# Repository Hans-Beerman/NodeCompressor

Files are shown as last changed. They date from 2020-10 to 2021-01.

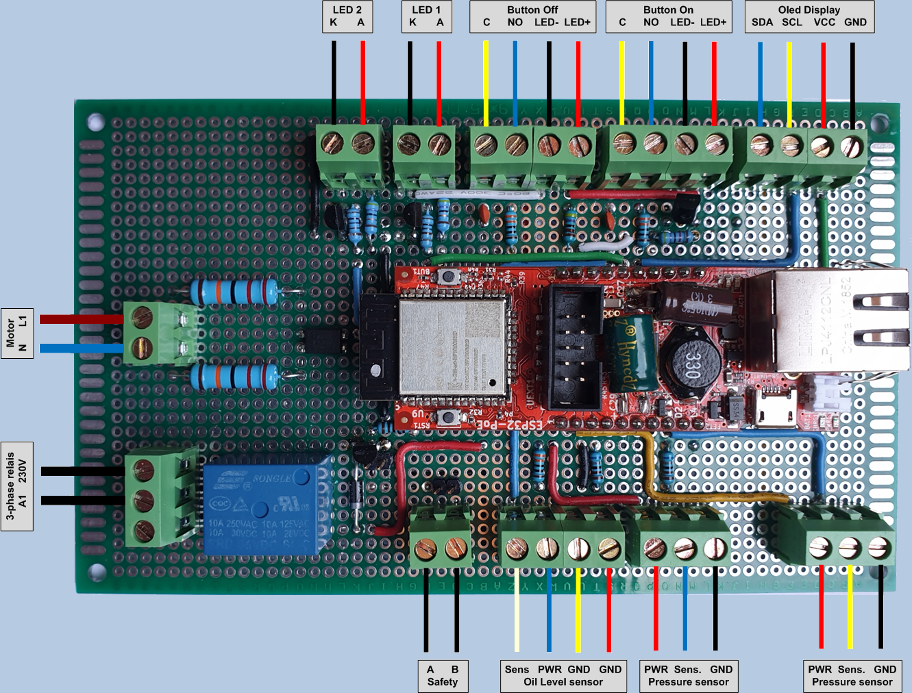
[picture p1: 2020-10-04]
Photos/Aansluitingen print V0.1 20200427.png

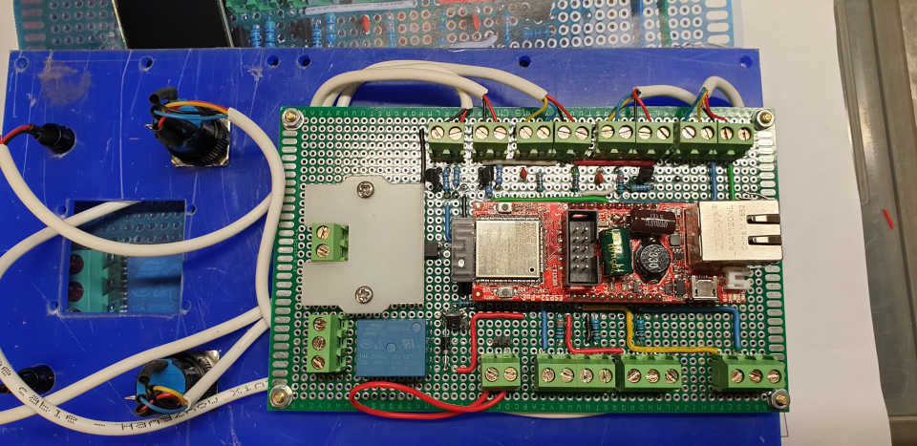
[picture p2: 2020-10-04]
Photos/CompressorNode-005.jpg

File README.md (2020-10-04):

**NodeCompressor**

NodeCompressor is a node, used at the MakerSpace Leiden, to control the main compressor. This repository has the following subdirs:

- **Drawings:**

Schematic of the wiring between the different modules used

- **KiCad\_files:**

The design of the PCB for the Node/Controller. De PCB in this design is not meant to be used for a real PCB. It is used as guideline for a handmade PCB

- **Photos:**

Some photos of the Node made.

- **PlatformIO\_Files:**

The source code for the Node and the display used. For the development of this software PlatformIO is used, an Extension on Visual Studio Code.

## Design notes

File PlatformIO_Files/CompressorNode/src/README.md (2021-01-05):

**Source code CompressorNode Makerspace Leiden**

Current version: V0.19 Concept

This repository contains the source code for the CompressorNode used at the Makerspace Leiden.

This CompressorNode is based on the use of the Olimex ESP32\_PoE. This small processor board is plugged on a backplane, details about this backplane can be found here, in KiCad files/CompressorNode:

[https://github.com/Hans-Beerman/NodeCompressor](https://github.com/Hans-Beerman/NodeCompressor)

This software is developed with Visual Studio Code in combination with the extension PlatformIO.

**This CompressorNode (the hardware in combination with the software) has the following features:**

- _Button On_: to manual switch on the compressor or cancel a manual switch off, waiting for the motor to stop running; 
- _Button Off_: to manual switch off the compressor, if the motor of the compressor is still running, switch off will be posponed until de motor is switched off by the pressure switch of the compressor. Pressing this switch for > 5s (when the motor is running) the compressor is switched off immediately;
- _Button On + Button Off_: if both buttons are pressed together for more than 5 seconds, while calibration mode is disabled, calibration mode will be disabled. Pressing both buttons together while calibration mode is enabled, calibration mode is disabled immediately. Also the duratution counters are saved in flash, every time calibration mode is enabled;
- _but1_: also used to toggle info / calibration mode on or off. but1 is the second button of the ESP32-PoE module. Press this button, when the node is running (the boot screen is not shown anymore). When info calibration mode is active each second e.g. the IP address and calibration info is logged to MQTT and telnet etc. Also the duratution counters are saved in flash, every time this button is pressed;
- _Automatic switch on_: switch the compressor on by means of dedicated MQTT messages
- _Automatic switch off_: switch the compressor off by means of dedicated MQTT mesages
- _Timeout_: the compressor will automatically switch off after a certain (in source code) configured timeout, currently after 60 minutes. Pressing Button On again (or sending MQTT command), while the compressor is switched on, will extend the timeout with 60 minutes. The auto switch off time will also be extended, with 60 minutes, when the compressor switches the motor of the compressor on or off;
- _Late hour disable_: after a configured time in the evening (currently 22:00 h) and before a configured time in the morning (currently 08:00 h) the compressor is disabled to prevent too much noise for our neighbors. This means the compressor will not start automatically by means of MQTT messages. Also the compressor will not start if the Button On is pressed normally;
- _Overrule late hour disable_: the late hour disable function can be overruled by pressing the Button On continuously for more than 10 seconds;
- _230VAC relais output:_ to switch the compressor on or off;
- _230VAC opto coupler input:_ This input is connected to one of the phases of the 3-phase motor of the compressor to detect if the motor is running or not;
- _2 LED&#39;s_: for signaling purposes. LED1 is on continuously when the compressor is switched on. LED2 is on continuously when the motor in the compressor is switched on. LED1 will flash for 5 s with 200 ms intervals if Button On is pressed during late hour disable. Both LED&#39;s will flash simultaneously with 600 ms intervals if there is an error which make it impossible to operate the compressor. The LED&#39;s will flash until the error is solved. The following two errors will disable de compressor:
  - Oil level too low;
  - Temperature to high;
- _Measurement of the machine temperature_: the temperature of the compressor is measured and reported via MQTT. The temperature is also shown on the display of the node. There are 2 temperature sensors, one is measuring the temperture of the motor, the other measures the temperature of the compressor;
- _Measurement of the oil level_: The oil level of the compressor is measured and reported via MQTT. This pressure is also shown on the display of the node;
- _Measurement of air pressure_: The air pressure, as produced by the compressor is measured and reported via MQTT. This pressure is also shown on the display of the node;
- _Status show on display_: There is a small Oled display (128x128 pixels) which shows status information about the node and the compressor.

**Setup of the software development environment**

See [https://github.com/dirkx/AccesSystem/tree/master/lib-arduino/ACNode](https://github.com/dirkx/AccesSystem/tree/master/lib-arduino/ACNode) for an introduction of how the software development environment can be setup. The description here however is based on the use of the Arduino software development tool. It will give you information about the libraries needed to compile the source code of the compressor node.

In addition to this description the following libraries are needed:

- _NTP_: NTP by Stefan Staub (#include <NTP.h>;) current version 1.4.

For more information about this library see:

[https://platformio.org/lib/show/5438/NTP](https://platformio.org/lib/show/5438/NTP)

This library is used to collect the correct local time via NTP;

- _DallasTemperature_: DallasTemperature by Miles Burton (#include <DallasTemperature.h>), current version 3.6.1, this library is used for the one wire temperature sensor based on the DS18B20;
- _U8x8lib_: U8g2 library by oliver (#include <U8x8lib.h>), current version 2.28.2, this library is used for the 128x128 pixels Oled display used.

WARNING:
The #define MQTT_MAX_PACKET_SIZE 254, in PubSubClient.h is overrulled in platformio.ini and set to 768:
In platformio,ini:
build_flags =
  '-DMQTT_MAX_PACKET_SIZE=768'

**Configuratie PlatformIO**

The configuration for this Project in PlatformIO is stored in the platformio.ini file, the content of this file is shown next, the IP address (192.168.5.95) is the current IP address of the node in the Makerspace, please change this to the correct IP address, given by the network to which the node is connected:

_;PlatformIO Project Configuration File_

_;_

_; Build options: build flags, source filter_

_; Upload options: custom upload port, speed and extra flags_

_; Library options: dependencies, extra library storages_

_; Advanced options: extra scripting_

_;_

_; Please visit documentation for the other options and examples_

_; https://docs.platformio.org/page/projectconf.html_

_[env:esp32-poe]_

_platform = espressif32_

_board = esp32-poe_

_framework = arduino_

_; enable ota_

_upload\_protocol = espota_

_upload\_port = 192.168.5.95_

_upload\_flags =_

_--port=8266_

_--auth=MyPassWoord_

_;upload\_port = /dev/ttyUSB0_

_monitor\_speed = 115200_

_board\_build.partitions = huge\_app.csv_

_; add local libraries_
_lib_deps =_
  _PubSubClient_
  _bblanchon/ArduinoJson_
  _Adafruit MAX31856 library_
  _PID_
  _ESP32WebServer_
  _NTP_
  _olikraus/U8g2_
  _milesburton/DallasTemperature_
  _adafruit/Adafruit GFX Library_
  _adafruit/Adafruit SSD1306_

_; evaluate C/C++ Preprocessor conditional syntax_
_lib\_ldf\_mode = deep+_

_monitor\_speed = 115200_
_board\_build.partitions = huge\_app.csv_

_build\_flags =_
  _; for debugging use next flag, otherwise make it comment_
  _;'-DDEBUGIT'_
  _; Default packet size is to small_
  _'-DMQTT\_MAX\_PACKET\_SIZE=768'_
  _; mqtt server address if not mqtt server MakerSpace_
  _;'-DMQTT\_SERVER="10.0.0.145"'_

**Configuration of the behaviour of the Node**

With the following parameters in the source code the behaviour of the node can be controlled:

- _Temperature limits:_

In main.cpp:

// temperature sensor

#define TEMP\_SENSOR\_LABEL1 ("Compressor") // label used in logging for temp. sensor 1

#define TEMP\_SENSOR\_LABEL2 ("Motor") // label used in logging for temp. sensor 2

#define TEMP\_REPORT\_ERROR1 ("temperature_sensor_1_(compressor)_error") // label used in reporting for temp. sensor 1

#define TEMP\_REPORT\_WARNING1 ("temperature_sensor_1_(compressor)_warning") // label used in reporting for temp. sensor 1

#define TEMP\_REPORT\1 ("temperature_sensor_1_(compressor)") // label used in reporting for temp. sensor 1

#define TEMP\_REPORT\_ERROR2 ("temperature_sensor_2_(motor)_error") // label used in reporting for temp. sensor 2

#define TEMP\_REPORT\_WARNING2 ("temperature_sensor_2_(motor)_warning") // label used in reporting for temp. sensor 2

#define TEMP\_REPORT2 ("temperature_sensor_2_(motor)") // label used in reporting for temp. sensor 2

#define TEMP\_IS\_HIGH\_LEVEL\_1 (60.0) // in degrees Celcius, used for temperature is high warning of sensor 1

#define TEMP_IS\_TOO\_HIGH\_LEVEL\_1 (90.0) // in degrees Celcius, used to disable the compressor when temperature is too high of sensor 1

#define TEMP_IS\_HIGH\_LEVEL\_2 (60.0) // in degrees Celcius, used for temperature is high warning of sensor 2

#define TEMP_IS\_TOO\_HIGH\_LEVEL\_2 (90.0) // in degrees Celcius, used to disable the compressor when temperature is too high of sensor 2

- _Pressure limits, used for safety:_
In main.cpp:

#define PRESSURE\_MAX\_LIMIT (12.0)   // Compressor must be switched off above this limit for safety
#define PRESSURE\_BELOW\_LIMIT (10.0) // If compressor was switched off because pressure was to high, 
                                    // compressor can be switched on again if pressure becomes below this limit
                                    
- _The LED's dim value:_
In main.cpp:

#define LED1\_DIM\_VALUE (50) // 0 - 255, 0 = LED1 is off
#define LED2\_DIM\_VALUE (50) // 0 - 255, 0 = LED2 is off

- _The time interval of the LED&#39;s in case of an error:_

In main.cpp:

// For LED&#39;s showing node error

#define BLINKING\_LED\_PERIOD (600) // in ms

- The time window between saves of the duration counters:

In main.cpp:

// for storage in EEProm of the duration counters

#define SAVE\_DURATION\_COUNTERS\_WINDOW (86400) // in seconds (86400 = 24 hour)

- _For the automatic timeout of the compressor:_

In main.cpp:

// for auto switch off of the compressor

#define AUTOTIMEOUT (30 \* 60 \* 1000) // default: in ms 30 \* 60 \* 1000 = 30 minutes

- _For the late hour disable function:_

In main.cpp:

// Compressor disabled (or not) at late hours:

// IF the compressor is not allowed at late hours (DISABLE\_COMPRESSOR AT LATE HOURS = true) the

// compressor will not switch on automatically (or by hand if the on button is pressed normally) from

// DISABLED\_TIME\_START to DISABLED\_START\_END

// Pressing the on button longer than MAX\_WAIT\_TIME\_BUTTON\_ON\_PRESSED will override this behaviour by

// switching on the compressor anyhow. In all cases the compressor will switch of after AUTOTIMEOUT (in ms)

// unless the button on is pressed again or a new auto on command is received while the compressor is

// already switched on. In both cases the time will be extended by AUTOTIMEOUT ms.

#define DISABLE\_COMPRESSOR\_AT\_LATE\_HOURS (true)

#define DISABLED\_TIME\_START (19) // in hour, time from which the compressor is not automatically switched on

#define DISABLED\_TIME\_END (8) // in hour, time to which the compressor is not automatically switched on

#define MAX\_WAIT\_TIME\_BUTTON\_ON\_PRESSED (10000) // in ms, time button on must be pressed to override late hour compressor disable

#define LED\_DISABLE\_DURATION (5000) // in ms, the time LED1 will flash if button on is pressed during late hour

#define LED\_DISABLE\_PERIOD (200) // in ms, the time LED1 will flash on/off

- _Time window for calibration buttons_

In main.cpp:

#define CALIB\_WINDOW\_TIME                     (5000) // in ms

- _Clear EEProm and cache, by pressing but1 of the ESP32-PoE module during boot for some time:_

In main.cpp:

#define MAX\_WAIT\_TIME\_BUTTON\_PRESSED (4000) // in ms

- _For logging to MQTT etc.:_

In main.cpp:

#define LOGGING\_ENABLED                       (true)  // to enable/disable logging

#define LOGGING\_TIME_\WINDOW                   (20000)  // in ms

- _The time between updates of the display:_

In OledDisplay.cpp:

// oled display

#define DISPLAY\_WINDOW (1000) // in ms, update display time

- _The time short status messages are shown on the bottom line of the display:_

In OledDisplay.cpp

#define KEEP\_STATUS\_LINE\_TIME (5000) // in ms, default = 5 s (5000), the time certain status messages are shown on the bottom line of the display

- _The time the oil level is too low, before an error is signaled:_

In OilLevelSensor.cpp:

#define MAX\_OIL\_LEVEL\_IS\_TOO\_LOW\_WINDOW (10000) // in ms default 10000 = 10 seconds. Error is signalled after this time window is passed

- _For calibration of the air pressure sensor:_

See the following parameters:

- Pressure calibrating values:

In PressureSensor.cpp:

#define PRESSURE\_CALIBRATE\_VALUE\_0\_5V (144) // in measured bits

#define PRESSURE\_CALIBRATE\_VALUE\_4\_5V (2600) // in measured bits

The air pressure sensor output is 0.5 V when the pressure is 0 bar.

The output is 4.5 V when the pressure is 12 bar

- _The time between samples of the air pressure:_

In PressureSensor.cpp:

#define PRESSURE\_SAMPLE\_WINDOW (1000) // in ms

- _The time the temperature is too high, before an error is signaled:_

In TempSensor.cpp:

#define MAX\_TEMP\_IS\_TOO\_HIGH\_WINDOW (10000) // in ms default 10000 = 10 seconds. Error is only signalled after this time window is passed

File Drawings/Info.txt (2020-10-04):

Uitleg optische niveau vloeistof sensor
https://www.electroschematics.com/optical-liquid-level-sensor/

Optische niveau vloeistof sensor
https://nl.aliexpress.com/item/32955443010.html

Druksensor:
https://www.amazon.com/Yosoo-Pressure-Transducer-Sensor-Diesel/dp/B01IR2MANC

DS18B20 temperatuursensor:
https://nl.banggood.com/DS18B20-Waterproof-Digital-Temperature-Temp-Sensor-Probe-1M-2M-3M-5M-10M-15M-p-1211828.html?ID=45764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

https://www.adafruit.com/product/381

Oled displays:
https://randomnerdtutorials.com/guide-for-oled-display-with-arduino/

https://www.adafruit.com/product/931

https://www.instructables.com/id/Monochrome-096-i2c-OLED-display-with-arduino-SSD13/

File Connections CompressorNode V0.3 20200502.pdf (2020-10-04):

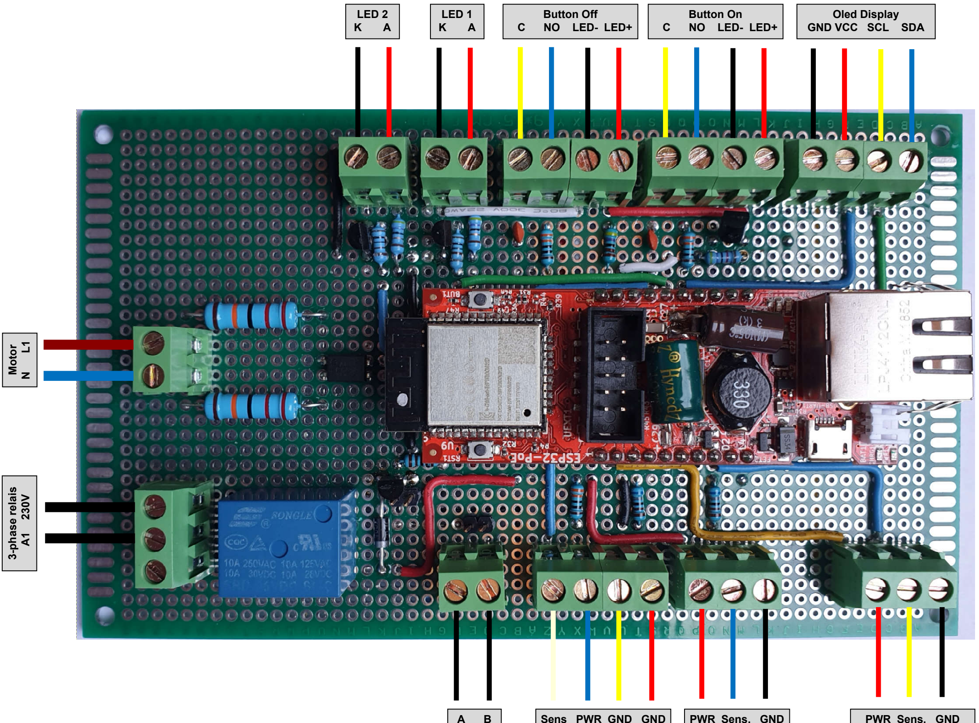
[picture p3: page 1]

Oled Display
GND VCC SCL SDA

Button On
C NO LED- LED+

LED 2
K A

LED 1
K A

Button Off
C NO LED- LED+

M

otor

N

L1

3-phase relais
A1 230V
A | B | Sens PWR GND GND | PWR Sens. GND | PWR Sens. GND

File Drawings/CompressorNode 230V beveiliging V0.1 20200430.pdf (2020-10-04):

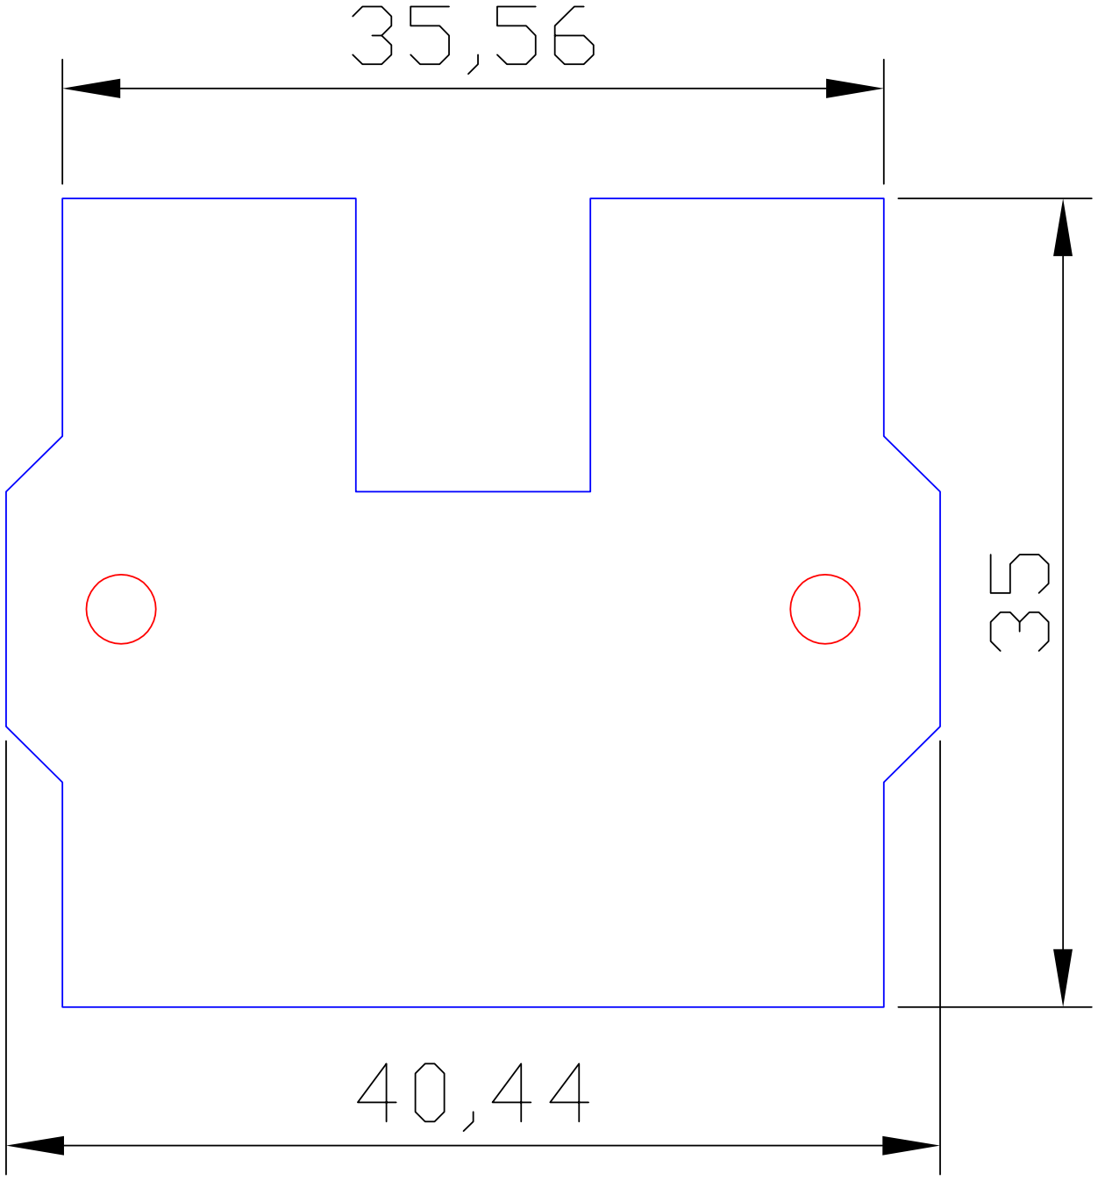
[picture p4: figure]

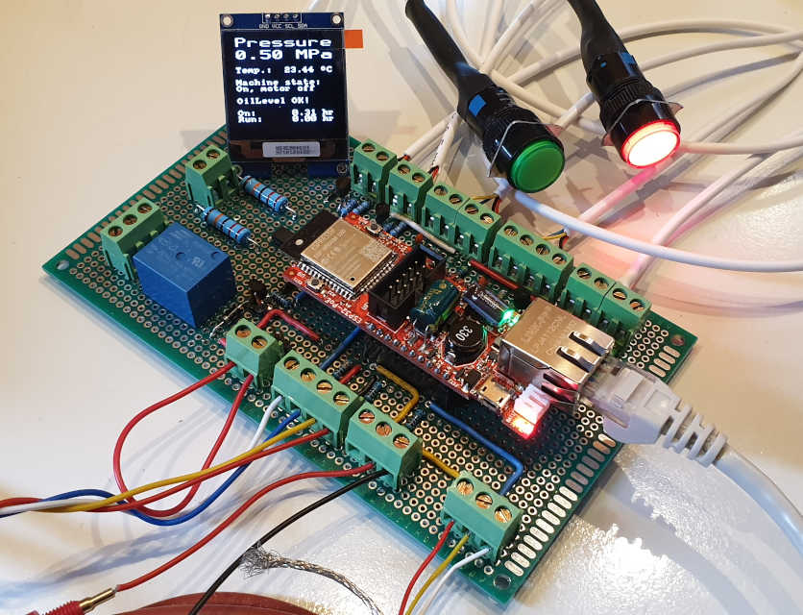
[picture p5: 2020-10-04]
Photos/CompressorNode-001.jpg

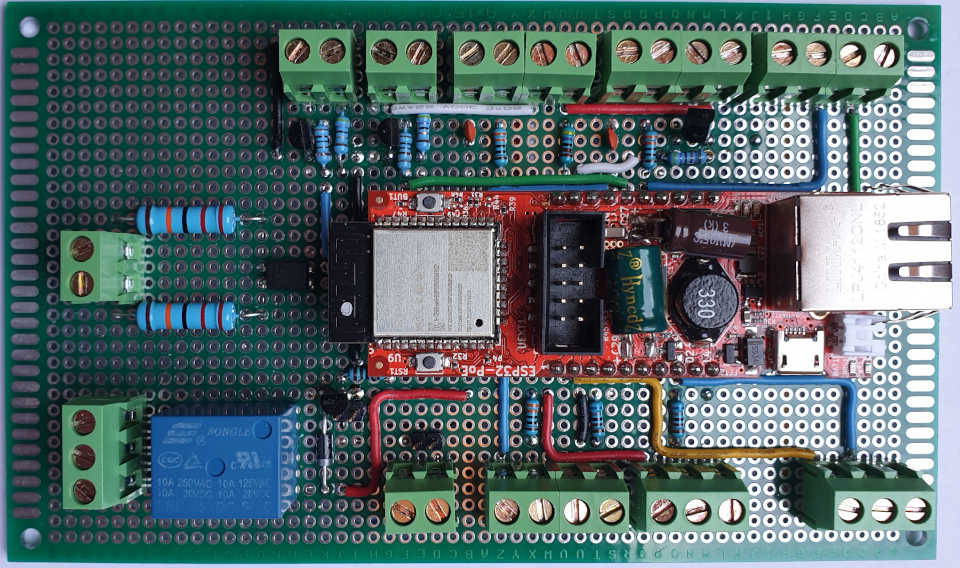
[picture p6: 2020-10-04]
Photos/CompressorNode-002.jpg

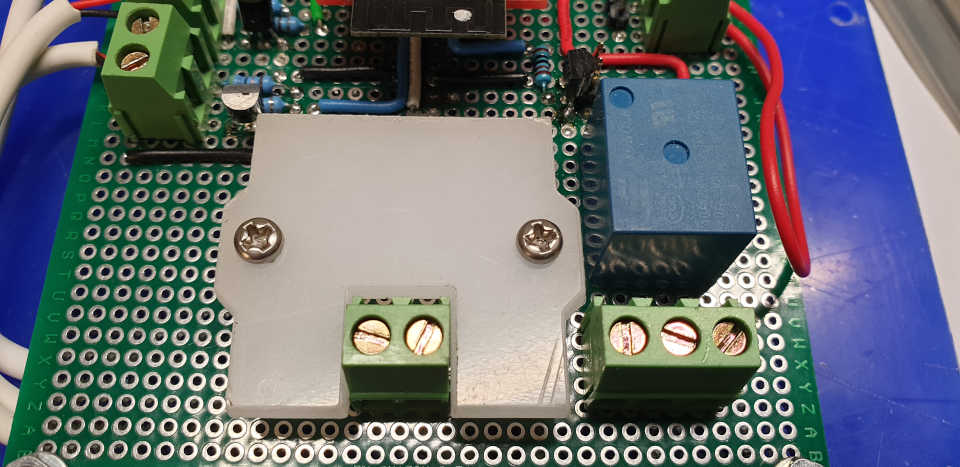
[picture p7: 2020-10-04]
Photos/CompressorNode-004.jpg

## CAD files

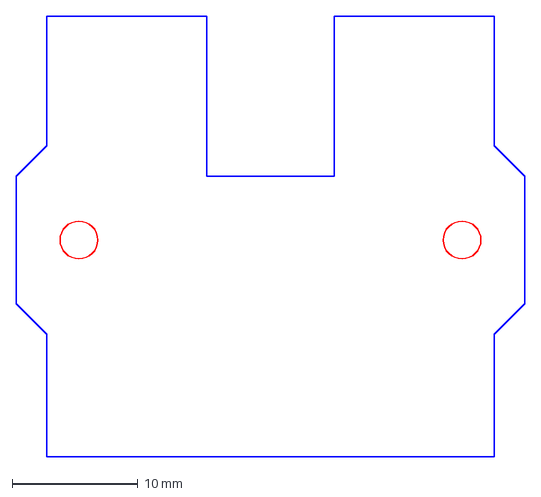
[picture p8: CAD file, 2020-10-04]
Drawings/CompressorNode 230V beveiliging V0.1 20200430.dxf
40.4 x 35.0 mm

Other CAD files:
Drawings/CompressorNode frontplaat txt font V0.2 20200501.dxf
Drawings/CompressorNode frontplaat verdana font V0.2 20200501.dxf

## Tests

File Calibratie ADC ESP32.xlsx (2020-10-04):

Spanning |  | ADC |  | Berekend
0.5 |  | 144 |  | 144
1 |  | 445 |  | 451
1.5 |  | 750 |  | 758
2 |  | 1060 |  | 1065
2.5 |  | 1366 |  | 1372
3 |  | 1680 |  | 1679
3.5 |  | 1985 |  | 1986
4 |  | 2290 |  | 2293
4.5 |  | 2600 |  | 2600
0
 | 0.9 | 0.8 | 200 | 1.378951458
 | 0.1 | 0 | 0
 |  |  | 200 | 1.378951458
 |  |  | 145.0377378

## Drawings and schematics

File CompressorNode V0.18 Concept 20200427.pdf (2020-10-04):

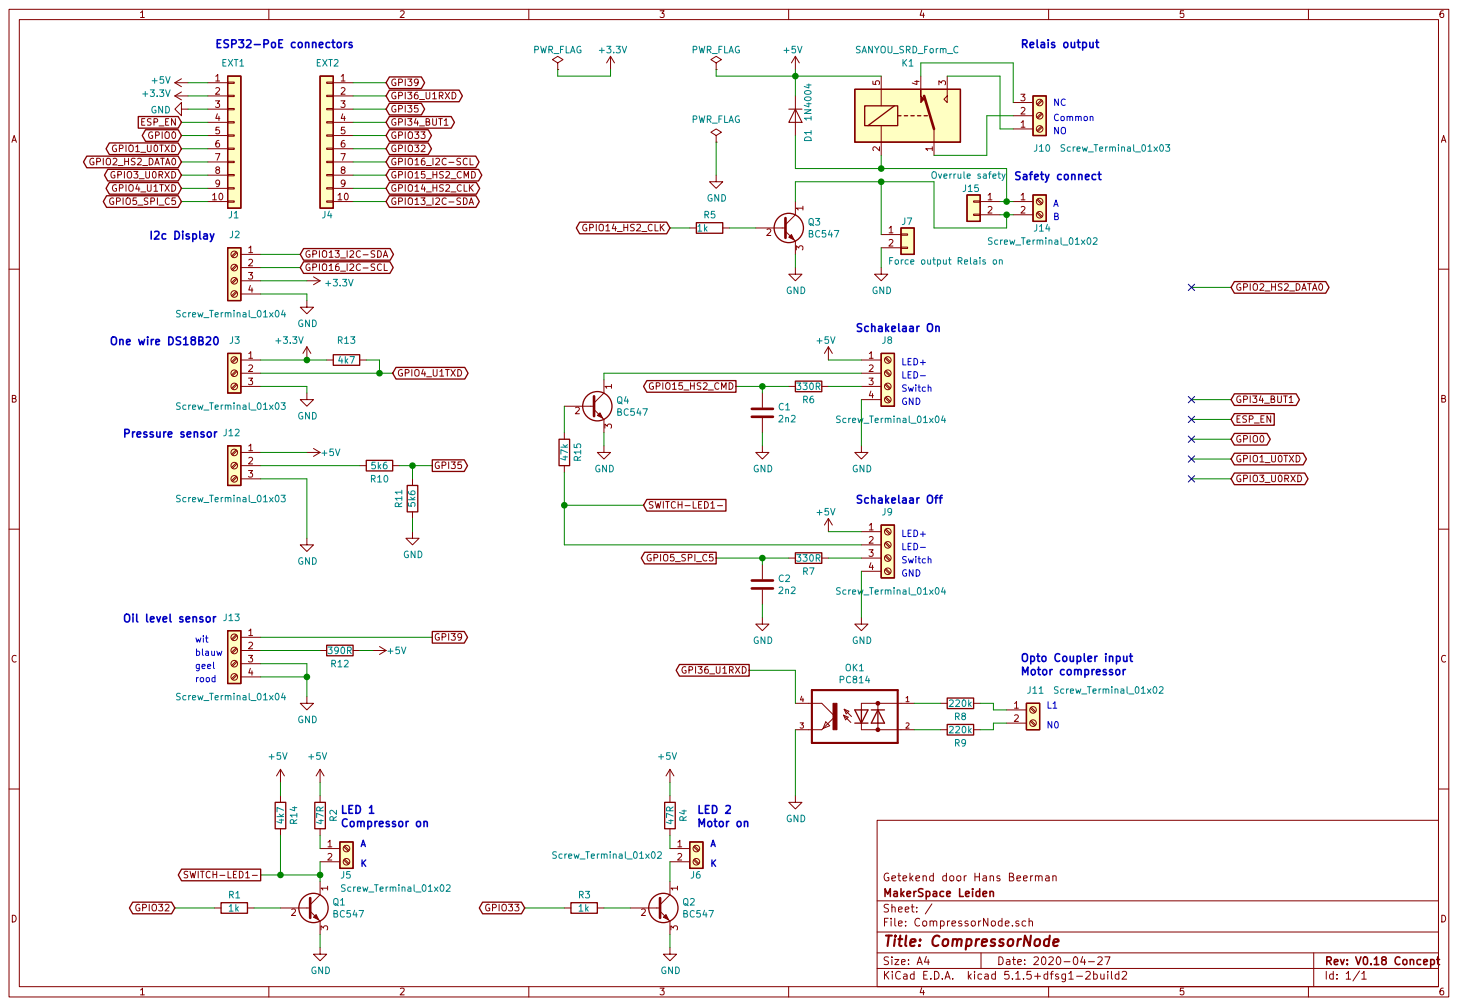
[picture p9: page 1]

File: CompressorNode.sch Sheet: / MakerSpace Leiden Getekend door Hans Beerman

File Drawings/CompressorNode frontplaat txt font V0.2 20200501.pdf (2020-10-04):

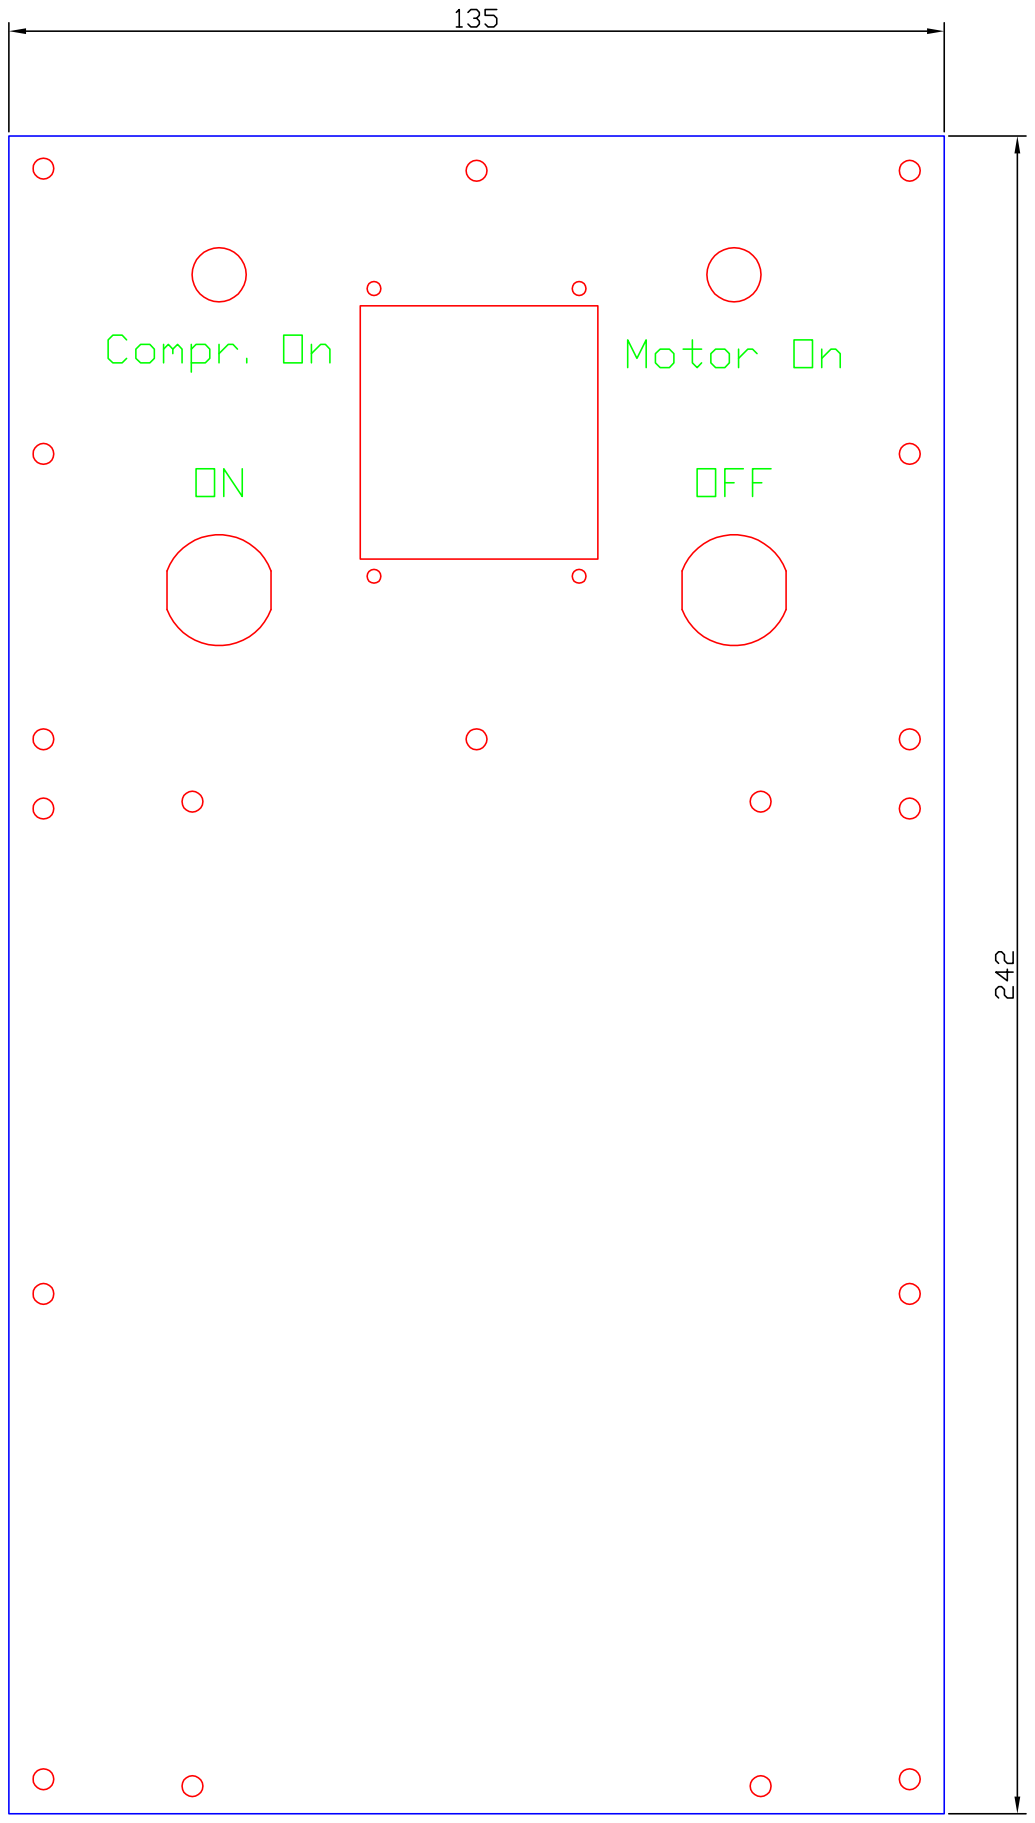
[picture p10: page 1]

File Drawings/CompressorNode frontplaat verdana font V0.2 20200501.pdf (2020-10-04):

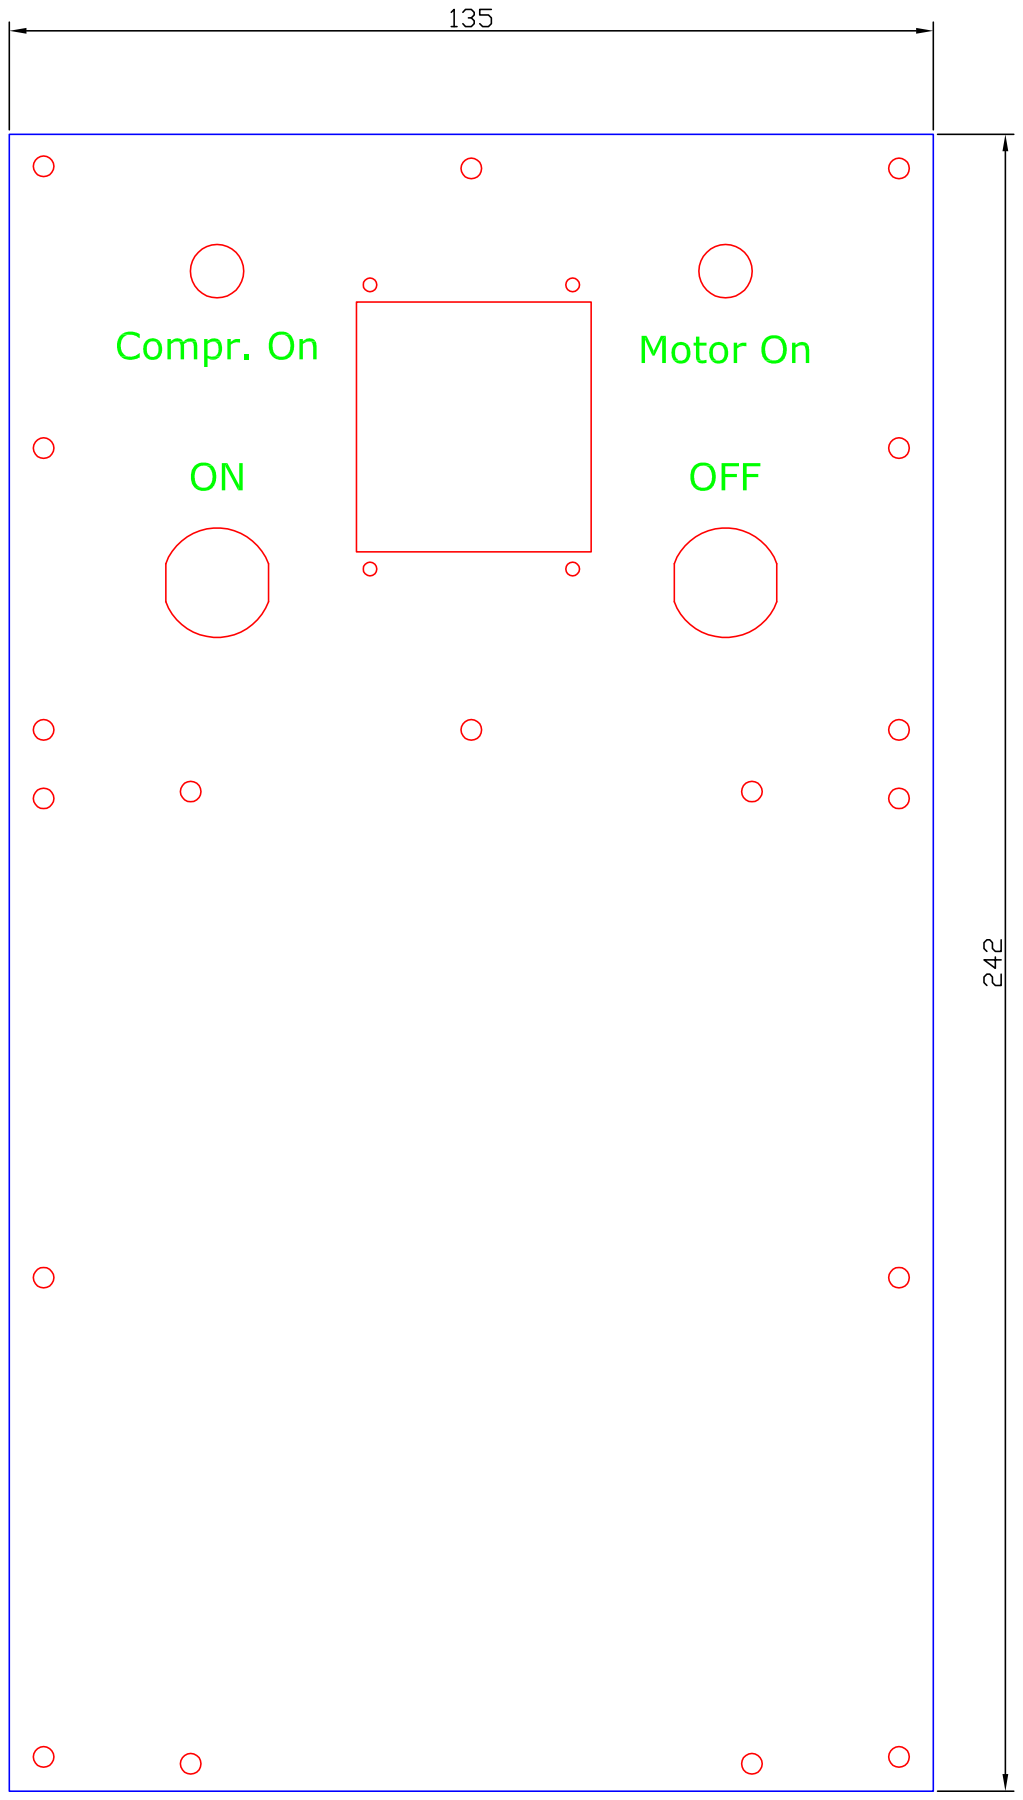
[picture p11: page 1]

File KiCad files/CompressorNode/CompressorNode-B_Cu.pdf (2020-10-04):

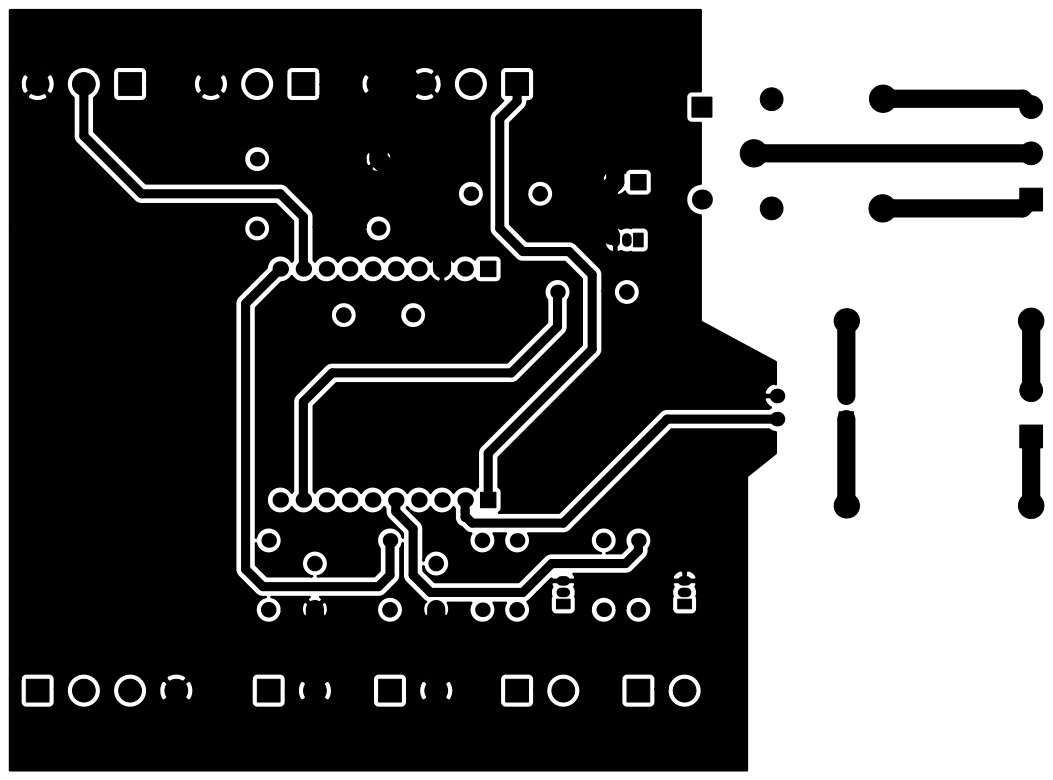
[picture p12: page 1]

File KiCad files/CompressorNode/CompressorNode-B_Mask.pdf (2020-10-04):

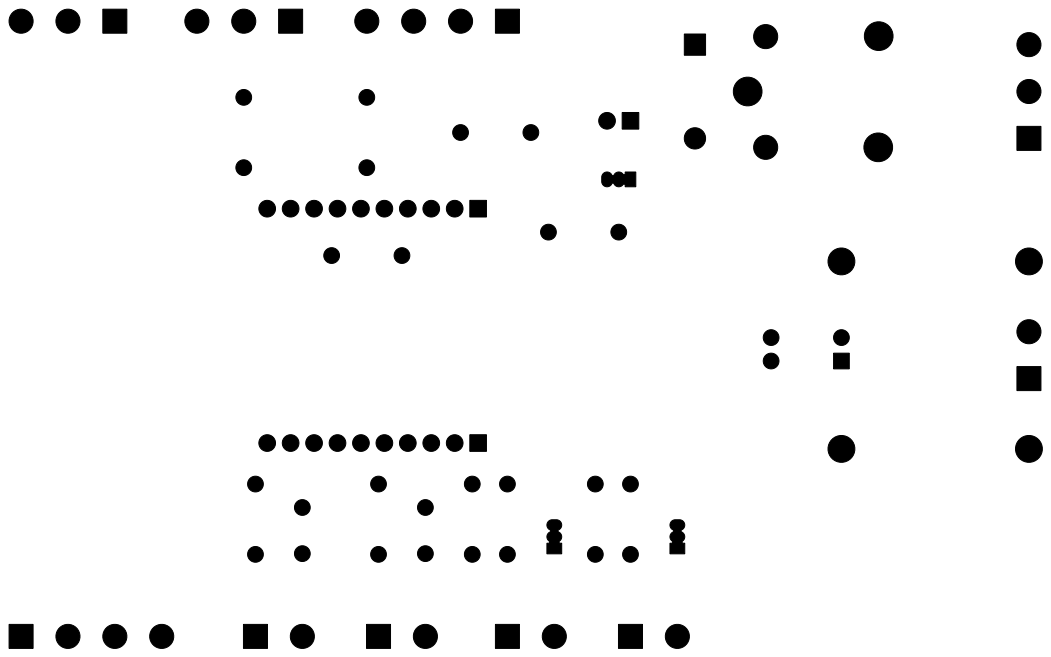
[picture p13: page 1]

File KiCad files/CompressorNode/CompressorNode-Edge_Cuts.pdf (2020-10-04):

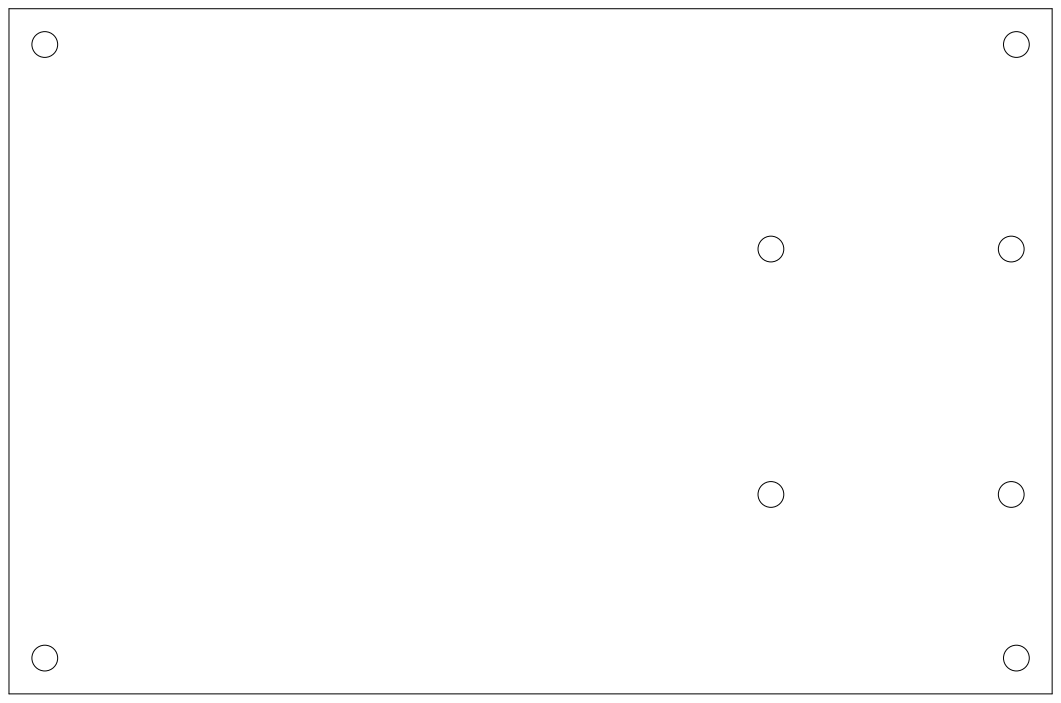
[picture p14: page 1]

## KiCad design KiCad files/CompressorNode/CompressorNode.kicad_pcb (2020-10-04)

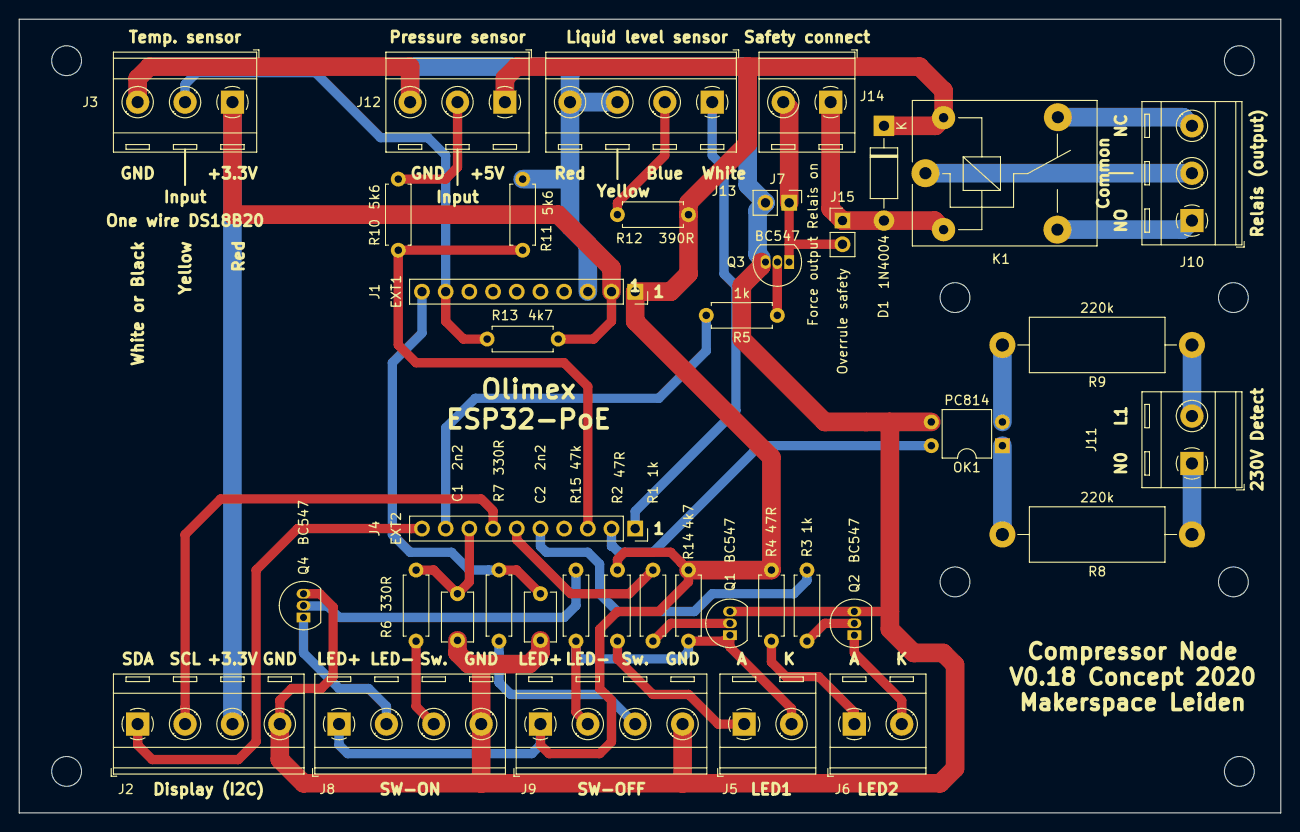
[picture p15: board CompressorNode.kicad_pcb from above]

Board: 2 copper layers, 135.3 x 85.1 mm, 39 parts (0 on the bottom side), 36 nets.

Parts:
C1, C2: 2n2; C_Disc_D5.1mm_W3.2mm_P5.00mm
D1: 1N4004; D_DO-41_SOD81_P10.16mm_Horizontal
J1: EXT1; PinSocket_1x10_P2.54mm_Vertical
J2, J8, J9, J13: Screw_Terminal_01x04; TerminalBlock_RND_205-00289_1x04_P5.08mm_Horizontal
J3, J10, J12: Screw_Terminal_01x03; TerminalBlock_RND_205-00288_1x03_P5.08mm_Horizontal
J4: EXT2; PinSocket_1x10_P2.54mm_Vertical
J5, J6, J11, J14: Screw_Terminal_01x02; TerminalBlock_RND_205-00287_1x02_P5.08mm_Horizontal
J7: Force output Relais on; PinHeader_1x02_P2.54mm_Vertical
J15: Overrule safety; PinHeader_1x02_P2.54mm_Vertical
K1: SANYOU_SRD_Form_C; Relay_SPDT_SANYOU_SRD_Series_Form_C
OK1: PC814; DIP-4_W7.62mm
Q1, Q2, Q3, Q4: BC547; TO-92_Inline
R1, R3, R5: 1k; R_Axial_DIN0207_L6.3mm_D2.5mm_P7.62mm_Horizontal
R2, R4: 47R; R_Axial_DIN0207_L6.3mm_D2.5mm_P7.62mm_Horizontal
R6, R7: 330R; R_Axial_DIN0207_L6.3mm_D2.5mm_P7.62mm_Horizontal
R8, R9: 220k; R_Axial_DIN0614_L14.3mm_D5.7mm_P20.32mm_Horizontal
R10, R11: 5k6; R_Axial_DIN0207_L6.3mm_D2.5mm_P7.62mm_Horizontal
R12: 390R; R_Axial_DIN0207_L6.3mm_D2.5mm_P7.62mm_Horizontal
R13, R14: 4k7; R_Axial_DIN0207_L6.3mm_D2.5mm_P7.62mm_Horizontal
R15: 47k; R_Axial_DIN0207_L6.3mm_D2.5mm_P7.62mm_Horizontal

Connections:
+3V3: J1.2, J2.3, J3.1, R13.2
+5V: D1.1, J1.1, J8.1, J9.1, J12.1, K1.5, R2.1, R4.1, R12.1, R14.1
GND: C1.2, C2.2, J1.3, J2.4, J3.3, J7.2, J8.4, J9.4, J12.3, J13.3, J13.4, OK1.3, Q1.3, Q2.3, Q3.3, Q4.3, R11.1
GPI35: J4.3, R10.1, R11.2
GPI36_U1RXD: J4.2, OK1.4
GPI39: J4.1, J13.1
GPIO4_U1TXD: J1.9, J3.2, R13.1
GPIO5_SPI_C5: C2.1, J1.10, R7.2
GPIO13_I2C-SDA: J2.1, J4.10
GPIO14_HS2_CLK: J4.9, R5.2
GPIO15_HS2_CMD: C1.1, J4.8, R6.2
GPIO16_I2C-SCL: J2.2, J4.7
GPIO32: J4.6, R1.2
GPIO33: J4.5, R3.2
unnamed: D1.2, J14.1, J15.1, K1.2
unnamed: J5.1, R2.2
unnamed: J6.1, R4.2
unnamed: J6.2, Q2.1
unnamed: J8.2, Q4.1
unnamed: J8.3, R6.1
unnamed: J9.3, R7.1
unnamed: J10.1, K1.3
unnamed: J10.2, K1.1
unnamed: J10.3, K1.4
unnamed: J11.1, R8.1
unnamed: J11.2, R9.1
unnamed: J12.2, R10.2
unnamed: J13.2, R12.2
unnamed: J7.1, J14.2, J15.2, Q3.1
unnamed: OK1.1, R8.2
unnamed: OK1.2, R9.2
unnamed: Q1.2, R1.1
unnamed: Q2.2, R3.1
unnamed: Q3.2, R5.1
unnamed: Q4.2, R15.1
SWITCH-LED1-: J5.2, J9.2, Q1.1, R14.2, R15.2

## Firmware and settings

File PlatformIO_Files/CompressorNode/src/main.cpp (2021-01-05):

/*
      Copyright 2015-2018 Dirk-Willem van Gulik <dirkx@webweaving.org>
      Copyright 2020      Hans Beerman <hans.beerman@xs4all.nl>
                          Stichting Makerspace Leiden, the Netherlands.

   Licensed under the Apache License, Version 2.0 (the "License");
   you may not use this file except in compliance with the License.
   You may obtain a copy of the License at

       http://www.apache.org/licenses/LICENSE-2.0

   Unless required by applicable law or agreed to in writing, software
   distributed under the License is distributed on an "AS IS" BASIS,
   WITHOUT WARRANTIES OR CONDITIONS OF ANY KIND, either express or implied.
   See the License for the specific language governing permissions and
   limitations under the License.
*/

#ifndef ESP32
#error "The CompressorNode uses an Olimex ESP32-PoE board only!"
#endif

#define ESP32_PoE
// #define OB_POLLING

// The GPIO pins used on the Olimax ESP32PoE
#define RELAY_GPIO                (14)  // digital output
#define ON_BUTTON                 (15)  // digital input
#define OFF_BUTTON                ( 5)  // digital input
#define OPTO1                     (36)  // digital input
#define LED1                      (32)  // digital output
#define LED2                      (33)  // digital output
#define OILLEVELSENSOR            (39)  // digital input
#define PRESSURESENSOR            (35)  // analog input
#define TEMPSENSOR                ( 4)  // one wire digital input
#define INFO_CALIBRATION_BUTTON   (34)  // this is the same as the CLEAR_EEPROM_AND_CACHE_BUTTON, BUT1 of the ESP32-PoE
                                        // pressing this button toggles Info / Calibration mode on of off. If on, IP address
                                        // and calibration information will be logged via MQTT and telnet

#include <Arduino.h>
#include <MachState.h>
#include <ACNode.h>
#include <WiredEthernet.h>
#include <SIG2.h>
#include <Cache.h>
#include <OptoDebounce.h>
#include <ButtonDebounce.h>
#include <WiFiUdp.h>
#include <EEPROM.h>
#include <NTP.h> // install NTP by Stefan Staub
//
// information about NTP.h, see: https://platformio.org/lib/show/5438/NTP
//
#include "TempSensor.h"
#include "PressureSensor.h"
#include "OledDisplay.h"
#include "OilLevelSensor.h"
#include ".passwd.h"
/* If using WiFi instead of a fixed ethernet connection, and/or OTA:

Add .passwd.h to the NodeCompressor/src directoy containing the following information

#pragma once

#define WIFI_NETWORK "YOUR_SSID"
#define WIFI_PASSWD "YOUR_PASSWD"

#define OTA_PASSWD "YOUR_OTA_PASSWD"
*/

WiFiUDP wifiUDP;
NTP ntp(wifiUDP);

// for test
#define MACHINE "bluecompressor"

// button on and button off
#define BUTTON_ON_PRESSED (LOW) // the input level of the GPIO port used for button on, if this button is pressed
#define BUTTON_OFF_PRESSED (LOW) // the input level of te GPIO port used for button off, if this button is pressed
#define BUTTON_INFO_CALIBRATION_PRESSED (LOW) // the input level of te GPIO port used for button info and calibrations, if this button is pressed

ButtonDebounce buttonOn(ON_BUTTON, 150 /* mSeconds */); // buttonOn is used to switch on the compressor
ButtonDebounce buttonOff(OFF_BUTTON, 150 /* mSeconds */); // buttonOff is used to switch off the compressor
ButtonDebounce buttonInfoCalibration(INFO_CALIBRATION_BUTTON, 150 /* mSeconds */); // buttonInfoCalibration is used to toggle Info / Calibration mode on/off

// 230VAC optocoupler
OptoDebounce opto1(OPTO1); // wired to N0 - L1 of 3 phase compressor motor, to detect if the motor has power (or not)

// temperature sensors
#define TEMP_SENSOR_LABEL1 ("Compressor") // label used in logging for temp. sensor 1
#define TEMP_SENSOR_LABEL2 ("Motor") // label used in logging for temp. sensor 2
#define TEMP_REPORT_ERROR1 ("temperature_sensor_1_(compressor)_error") // label used in reporting for temp. sensor 1
#define TEMP_REPORT_WARNING1 ("temperature_sensor_1_(compressor)_warning") // label used in reporting for temp. sensor 1
#define TEMP_REPORT1 ("temperature_sensor_1_(compressor)") // label used in reporting for temp. sensor 1
#define TEMP_REPORT_ERROR2 ("temperature_sensor_2_(motor)_error") // label used in reporting for temp. sensor 2
#define TEMP_REPORT_WARNING2 ("temperature_sensor_2_(motor)_warning") // label used in reporting for temp. sensor 2
#define TEMP_REPORT2 ("temperature_sensor_2_(motor)") // label used in reporting for temp. sensor 2
// Temperature warning and error levels
#define TEMP_IS_HIGH_LEVEL_1 (75.0) // in degrees Celcius, used for temperature is high warning of sensor 1
#define TEMP_IS_TOO_HIGH_LEVEL_1 (90.0) // in degrees Celcius, used to disable the compressor when temperature is too high of sensor 1
#define TEMP_IS_HIGH_LEVEL_2 (70.0) // in degrees Celcius, used for temperature is high warning of sensor 2
#define TEMP_IS_TOO_HIGH_LEVEL_2 (90.0) // in degrees Celcius, used to disable the compressor when temperature is too high of sensor 2


// Pressure limits, used for safety
#define PRESSURE_MAX_LIMIT (12.0)   // Compressor must be switched off above this limit for safety
#define PRESSURE_BELOW_LIMIT (10.0) // If compressor was switched off because pressure was to high, 
                                    // compressor can be switched on again if pressure becomes below this limit

// NTP update window
#define NTP_UPDATE_WINDOW (1000) // in ms

// for auto reset node at configured hour
#define AUTO_RESET_ENABLED true // if auto reset is enabled
#define AUTO_RESET_HOUR 1 // Reset node at 1:00 hr
int previousHour = AUTO_RESET_HOUR;

// setting PWM properties for LED's
#define PWM_FREQ (5000)
#define PWM_LED_CHANNEL1 (0)
#define PWM_LED_CHANNEL2 (1)
#define PWM_RESOLUTION (8)
#define LED1_DIM_VALUE (50) // 0 - 255, 0 = LED1 is off
#define LED2_DIM_VALUE (50) // 0 - 255, 0 = LED2 is off

// For LED's showing node error
#define BLINKING_LED_PERIOD (600) // in ms

// for storage in EEProm of the duration counters
#define SAVE_DURATION_COUNTERS_WINDOW (86400) // in seconds (86400 = 24 hour)

#define DURATION_DIR_PREFIX "/init"
#define DURATION_FILE_PREFIX "/duration"

// for auto switch off of the compressor
#define AUTOTIMEOUT (60 * 60 * 1000) // default: in ms 60 * 60 * 1000 = 60 minutes

// Compressor disabled (or not) at late hours:
// IF the compressor is not allowed at late hours (DISABLE_COMPRESSOR AT LATE HOURS = true) the 
// compressor will not switch on automatically (or by hand if the on button is pressed normally) from
// DISABLED_TIME_START to DISABLED_START_END
// Pressing the on button longer than MAX_WAIT_TIME_BUTTON_ON_PRESSED will override this behaviour by
// switching on the compressor anyhow. In all cases the compressor will switch of after AUTOTIMEOUT (in ms)
// unless the button on is pressed again or a new auto on command is received while the compressor is
// already switched on. In both cases the time will be extended by AUTOTIMEOUT ms.
#define DISABLE_COMPRESSOR_AT_LATE_HOURS      (true)
#define DISABLED_TIME_START                   (19) // in hour, time from which the compressor is not automatically switched on
#define DISABLED_TIME_END                     (7) // in hour, time to which the compressor is not automatically switched on
#define MAX_WAIT_TIME_BUTTON_ON_PRESSED       (10000)  // in ms, time button on must be pressed to override late hour compressor disable
#define MAX_WAIT_TIME_BUTTON_OFF_PRESSED      (5000)  // in ms, time button off must be pressed to switch compressor off immediately
#define LED_DISABLE_DURATION                  (5000)  // in ms, the time LED1 will flash if button on is pressed during late hour
#define LED_DISABLE_PERIOD                    (200)  // in ms, the time LED1 will flash on/off
#define AUTOMATIC_EXTEND_AUTOTIMEOUT          (true)
#define AUTO_EXTEND_PRESSURE_LIMIT            (7) // extend auto timeout if pressure is below limit while compressor is on

// time window for calibration buttons
#define CALIB_WINDOW_TIME                     (5000) // in ms

// Clear EEProm button
// Press BUT1 on Olimex ESP32 PoE module before (re)boot of node
// keep BUT1 pressed for at least 5 s
// After the release of BUT1 node will restart with empty EEProm
#define CLEAR_EEPROM_AND_CACHE_BUTTON         (34)
#define CLEAR_EEPROM_AND_CACHE_BUTTON_PRESSED (LOW)

#define MAX_WAIT_TIME_BUTTON_PRESSED          (4000)  // in ms

// for logging to MQTT etc.
#define LOGGING_ENABLED                       (true)  // to enable/disable logging
#define LOGGING_TIME_WINDOW                   (20000)  // in ms


// for testing the timing of the different loops etc.
// #define TEST_TIMING
#define TEST_TIME_LIMIT (100)

#ifdef WIFI_NETWORK
ACNode node = ACNode(MACHINE, WIFI_NETWORK, WIFI_PASSWD);
#else
ACNode node = ACNode(MACHINE);
#endif

MqttLogStream mqttlogStream = MqttLogStream();
TelnetSerialStream telnetSerialStream = TelnetSerialStream();

#ifdef OTA_PASSWD
OTA ota = OTA(OTA_PASSWD);
#endif

#define NEVER (0)

struct {
  const char * label;                   // name of this state
  LED::led_state_t ledState;            // flashing pattern for the aartLED. Zie ook https://wiki.makerspaceleiden.nl/mediawiki/index.php/Powernode_1.1.
  time_t maxTimeInMilliSeconds;         // how long we can stay in this state before we timeout.
  machinestates_t failStateOnTimeout;   // what state we transition to on timeout.
} state[RUNNING + 1] =
{
  { "Booting",              LED::LED_ERROR,           120 * 1000, REBOOT },
  { "Out of order",         LED::LED_ERROR,           120 * 1000, REBOOT },
  { "Rebooting",            LED::LED_ERROR,           120 * 1000, REBOOT },
  { "Transient Error",      LED::LED_ERROR,           120 * 1000, REBOOT },
  { "No network",           LED::LED_FLASH,           120 * 1000, REBOOT },
  { "Waiting for card",     LED::LED_IDLE,            NEVER, REBOOT },
  { "Checking card",        LED::LED_IDLE,            NEVER, REBOOT },
  { "Compressor switched off", LED::LED_IDLE,         NEVER, SWITCHEDOFF},
  { "Powered - motor off",  LED::LED_IDLE,            NEVER, POWERED },
  { "Powered - motor running", LED::LED_ON,           NEVER, RUNNING },
};

unsigned long laststatechange = 0;
static machinestates_t laststate = BOOTING;
machinestates_t machinestate = BOOTING;

unsigned long powered_total = 0, powered_last;
unsigned long running_total = 0, running_last;

float powered = 0.0;
float running = 0.0;

unsigned long lastSavedPoweredCounter = 0;
unsigned long lastSavedRunningCounter = 0;

// pressure sensor
PressureSensor thePressureSensor(PRESSURE_MAX_LIMIT, PRESSURE_BELOW_LIMIT);

// temperature sensors
TemperatureSensor theTempSensor1(TEMP_IS_HIGH_LEVEL_1, TEMP_IS_TOO_HIGH_LEVEL_1, TEMP_SENSOR_LABEL1);
TemperatureSensor theTempSensor2(TEMP_IS_HIGH_LEVEL_2, TEMP_IS_TOO_HIGH_LEVEL_2, TEMP_SENSOR_LABEL2);

// oil level sensor
OilLevelSensor theOilLevelSensor;

// OledDisplay
OledDisplay theOledDisplay;

unsigned long blinkingLedNextTime = 0;
bool blinkingLedIsOn = false;
bool ledIsBlinking = false;

char reportStr[128];

char ntpDateTimeStr[64];

unsigned long nextLoggingTime = 0;

unsigned long DurationCounterSave;

unsigned long verifyButtonOnPressedTime;
unsigned long verifyButtonOffPressedTime;
bool verifyButtonOnIsStillPressed = false;
bool verifyButtonOffIsStillPressed = false;
bool isManualSwitchedOn = false;
bool isManualSwitchedOnVerifyOverride = false;
bool isManualSwitchedOffVerifyOverride = false;
bool isManualSwitchedOff = false;
bool isManualSwitchedOffWait = false;
bool isManualTimeOutExtended = false;
bool isAutomaticTimeOutExtended = false;
bool checkPressureTimeOutExtend = false;

unsigned long ledDisableTime = 0;
unsigned long nextLedDisableTime = 0;
bool showLedDisable = false;
bool disableLedIsOn = false;

unsigned long autoPowerOff;
bool compressorIsOn = false;
bool CompressorMustBeSwitchedOff = false;

bool automaticStopReceived = false;
bool automaticPowerOnReceived = false;
bool automaticPowerOnDenied = false;

bool ErrorPressureIsTooHigh = false;
bool showErrorPressureIsTooHigh = false;
bool showPressureIsOK = false;

bool checkCalibButtonsPressed = false;
long int checkCalibTimeOut = 0;
bool showInfoAndCalibration = false;
IPAddress theLocalIPAddress;

unsigned long nextNTPUpdateTime = 0;


// for testing loop timing
long long prevTime = 0;
int waitcount = 0;
int placeCount = 0;
long long averageTime[40] = {0,0,0,0,0,0,0,0,0,0,0,0,0,0,0,0,0,0,0,0,0,0,0,0,0,0,0,0,0,0,0,0,0,0,0,0,0,0,0,0,};

void checkClearEEPromAndCacheButtonPressed(void) {
  unsigned long ButtonPressedTime;
  unsigned long prevSecs;
  bool firstTime = true;

  // check CLEAR_EEPROM_AND_CACHE_BUTTON pressed
  pinMode(CLEAR_EEPROM_AND_CACHE_BUTTON, INPUT);
  // check if button is pressed for at least 4 s
  Log.println("Checking if the button is pressed for clearing EEProm and cache");

	
  if (digitalRead(CLEAR_EEPROM_AND_CACHE_BUTTON) == CLEAR_EEPROM_AND_CACHE_BUTTON_PRESSED) {
    theOledDisplay.clearEEPromWarning();
    ButtonPressedTime = millis();  
    prevSecs = MAX_WAIT_TIME_BUTTON_PRESSED / 1000;
    Log.print("Keep the button pressed at least: ");
    Log.print(prevSecs);
    Log.println(" s");
    while (digitalRead(CLEAR_EEPROM_AND_CACHE_BUTTON) == CLEAR_EEPROM_AND_CACHE_BUTTON_PRESSED) {
      if ((millis() - ButtonPressedTime) >= MAX_WAIT_TIME_BUTTON_PRESSED) {
        if (firstTime) {
          Log.println("");
          Log.println("Please release the button");
          theOledDisplay.showStatus(RELEASEBUTTON);
          firstTime = false;
        }
      }
    }

    if ((millis() - ButtonPressedTime) >= MAX_WAIT_TIME_BUTTON_PRESSED) {
      Log.println("");
      Log.print("Button for clearing EEProm and cache was pressed for more than ");
      Log.print(MAX_WAIT_TIME_BUTTON_PRESSED / 1000);
      Log.println(" s, EEProm and Cache will be cleared!");
      theOledDisplay.clearEEPromMessage();
      theOledDisplay.showStatus(NOSTATUS);
      // Clear EEPROM
      EEPROM.begin(1024);
      wipe_eeprom();
      Log.println("EEProm cleared!");
      theOledDisplay.EEPromCleared();      
      // Clear cache
      prepareCache(true);
      // Clear duration counter file
      String path = DURATION_DIR_PREFIX + (String)DURATION_FILE_PREFIX;
      if (SPIFFS.exists(path)) {
        SPIFFS.remove(path);
      } 
      theOledDisplay.cacheCleared();
      Log.println("Cache cleared!");
      // wait until button is released, than reboot
      while (digitalRead(CLEAR_EEPROM_AND_CACHE_BUTTON) == CLEAR_EEPROM_AND_CACHE_BUTTON_PRESSED) {
        // do nothing here
      }
      Log.println("Node will be restarted");
      theOledDisplay.showStatus(NODEREBOOT);
      // restart node
      ESP.restart();
    } else {
      Log.println("\rButton was not (or not long enough) pressed to clear EEProm and cache");
    }
  }
}

void saveDurationCounters() {
  unsigned long tmpCounter1;
  unsigned long tmpCounter2;

  if (machinestate >= POWERED) {
    tmpCounter1 = powered_total + (millis() - powered_last) / 1000;
  } else {
    tmpCounter1 = powered_total;
  }

  if (machinestate == RUNNING) {
    tmpCounter2 = running_total + (millis() - running_last) / 1000;
  } else {
    tmpCounter2 = running_total;
  }

  if ((tmpCounter1 != lastSavedPoweredCounter) || (tmpCounter2 != lastSavedRunningCounter)) {
    String path = DURATION_DIR_PREFIX + (String)DURATION_FILE_PREFIX;
    File durationFile;
    unsigned int writeSize;
    durationFile = SPIFFS.open(path, "wb");
    if(!durationFile) {
      Log.print("There was an error opening the ");
      Log.print(DURATION_DIR_PREFIX);
      Log.print(DURATION_FILE_PREFIX);
      Log.println(" file for writing");
      return;
    }
    writeSize = durationFile.write((byte*)&tmpCounter1, sizeof(tmpCounter1));
    if (writeSize != sizeof(tmpCounter1)) {
      Log.print("ERROR --> powered_total: ");
      Log.print(tmpCounter1);
      Log.println(" NOT stored in SPIFFS");
      durationFile.close();
      return;
    }

    writeSize = durationFile.write((byte*)&tmpCounter2, sizeof(tmpCounter2));
    if (writeSize != sizeof(tmpCounter2)) {
      Log.print("ERROR --> running_total: ");
      Log.print(tmpCounter2);
      Log.println(" NOT stored in SPIFFS");
      durationFile.close();
      return;
    }
    durationFile.close();
  }
}

void loadDurationCounters() {
  String path = DURATION_DIR_PREFIX + (String)DURATION_FILE_PREFIX;
  File durationFile;
  unsigned int readSize;

  if(!SPIFFS.begin(false)){
    Log.println("An Error has occurred while mounting SPIFFS");
    return;
  }
  if (SPIFFS.exists(path)) {
    durationFile = SPIFFS.open(path, "rb");
    if(!durationFile) {
      Log.print("There was an error opening the ");
      Log.print(DURATION_DIR_PREFIX);
      Log.print(DURATION_FILE_PREFIX);
      Log.println(" file for reading");
      return;
    }
    durationFile.setTimeout(0);
    readSize = durationFile.readBytes((char*)&powered_total, sizeof(powered_total));
    if (readSize == sizeof(powered_total)) {
     powered = (float)powered_total / 3600.0;
    } else {
      Log.print("There was an error reading powered_total from ");
      Log.print(DURATION_DIR_PREFIX);
      Log.println(DURATION_FILE_PREFIX);
      durationFile.close();
      return;
    }
    readSize = durationFile.readBytes((char*)&running_total, sizeof(running_total));
    if (readSize == sizeof(running_total)) {
      running = (float)running_total / 3600.0;
    } else {
      Log.print("There was an error reading powered_total from ");
      Log.print(DURATION_DIR_PREFIX);
      Log.println(DURATION_FILE_PREFIX);
      durationFile.close();
      return;
    }
 
    durationFile.close();
    return;
  } else {
    Log.print("The file ");
    Log.print(DURATION_DIR_PREFIX);
    Log.print(DURATION_FILE_PREFIX);
    Log.println(" is not available!");
  }
}
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
void loop() {
#ifdef TEST_TIMING
  prevTime = millis();
  placeCount = 0;
#endif

  node.loop();
#ifdef TEST_TIMING
  testLoopTiming("na node.loop");
#endif

  theTempSensor1.loop();
  theTempSensor2.loop();
#ifdef TEST_TIMING
  testLoopTiming("na theTempSensor1 en 2.loop");
#endif

  thePressureSensor.loop();
#ifdef TEST_TIMING
  testLoopTiming("na thePressureSensor.loop");
#endif

  if (!showLedDisable) {
    theOledDisplay.loop(oilLevelIsTooLow, ErrorOilLevelIsTooLow, 
                        theTempSensor1.temperature, theTempSensor1.tempIsHigh, theTempSensor1.ErrorTempIsTooHigh, 
                        theTempSensor2.temperature, theTempSensor2.tempIsHigh, theTempSensor2.ErrorTempIsTooHigh, ErrorPressureIsTooHigh,
                        pressure, machinestate, 
                        powered_total, powered_last,
                        running_total, running_last);
  }
#ifdef TEST_TIMING
  testLoopTiming("na theOledDisplay.loop");
#endif

  compressorLoop();
#ifdef TEST_TIMING
  testLoopTiming("na compressorLoop");
#endif


  buttons_optocoupler_loop();
#ifdef TEST_TIMING
  testLoopTiming("na buttons_optocoupler.loop");
#endif


  theOilLevelSensor.loop();
#ifdef TEST_TIMING
  testLoopTiming("na theOilLevelSensor.loop");
#endif

  if (laststate != machinestate) {
    Log.print("Changed from state ");
    Log.print(state[laststate].label);
    Log.print(" to state ");
    Log.println(state[machinestate].label);

    if (machinestate >= POWERED && laststate < POWERED) {
      powered_last = millis();
    } else if (laststate >= POWERED && machinestate < POWERED) {
      powered_total += (millis() - powered_last) / 1000;
      powered = (float)powered_total / 3600.0;
    };
    if (machinestate == RUNNING && laststate < RUNNING) {
      running_last = millis();
    } else if (laststate == RUNNING && machinestate < RUNNING) {
      running_total += (millis() - running_last) / 1000;
      running = (float)running_total / 3600.0;
    };
    laststate = machinestate;
    laststatechange = millis();
  }

  if (state[machinestate].maxTimeInMilliSeconds != NEVER &&
      ((millis() - laststatechange) > state[machinestate].maxTimeInMilliSeconds)) {
    laststate = machinestate;
    machinestate = state[machinestate].failStateOnTimeout;
//    Debug.print("Time-out; transition from ");
//    Debug.print(state[laststate].label);
//    Debug.print(" to ");
//    Debug.println(state[machinestate].label);
    return;
  };
  
  switch (machinestate) {
    case REBOOT:
      saveDurationCounters();
      node.delayedReboot();
      break;

    case SWITCHEDOFF:
      // Compressor switched off completely.
      if (compressorIsOn) {
        CompressorMustBeSwitchedOff = false;
        digitalWrite(RELAY_GPIO, 0);
        // digitalWrite(LED1, 0);
        // digitalWrite(LED2, 0);
        ledcWrite(PWM_LED_CHANNEL1, 0);
        ledcWrite(PWM_LED_CHANNEL2, 0);
        compressorIsOn = false;
        Log.println("Compressor switched off");
      }
      break;

    case POWERED:
      // Compressor switched on, but motor is off
      if (!compressorIsOn) {
        digitalWrite(RELAY_GPIO, 1);
        // digitalWrite(LED1, 1);
        // digitalWrite(LED2, 0);
        ledcWrite(PWM_LED_CHANNEL1, LED1_DIM_VALUE);
        ledcWrite(PWM_LED_CHANNEL2, 0);
        compressorIsOn = true;
        Log.println("Compressor switched on, motor is off");
      }
      break;
    case RUNNING:
      // Compressor switched on and motor is running
      break;

    case WAITINGFORCARD:
    case CHECKINGCARD:
      // should not come here, so bail out
      machinestate = REBOOT;
      break;
    case TRANSIENTERROR:
    case OUTOFORDER:
    case NOCONN:
    case BOOTING:
      break;
  };

#ifdef TEST_TIMING
  testLoopTiming("na state machine (einde loop)");

  waitcount++;
  if (waitcount >= 1000) {
    waitcount = 0;
  }
#endif
}

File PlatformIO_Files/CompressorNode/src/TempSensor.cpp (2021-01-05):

#include "TempSensor.h"
#include "OledDisplay.h"
#include <OneWire.h> 
#include <ACNode.h>

#ifndef TEMPSENSOR
#define TEMPSENSOR      ( 4)  // one wire digital input (GPIO4)
#endif

// One Wire input port for temperature sensor
#define ONE_WIRE_BUS (TEMPSENSOR)

#define TEMP_RESOLUTION (12) // 9, 10, 11 or 12 bit resolution of the ADC in the temperature sensor
#define MAX_TEMP_CONVERSIONTIME (750) // in ms
#define MAX_NR_OF_TRIES 3

#define MAX_TEMP_IS_TOO_HIGH_WINDOW (10000) // in ms default 10000 = 10 seconds. Error is only signalled after this time window is passed

// temperature sensor
OneWire oneWire(ONE_WIRE_BUS); // used for the temperature sensor
DallasTemperature sensorTemp(&oneWire);

int currentTempSensor = 0;

TemperatureSensor::TemperatureSensor(float tempIsHighLevel, float tempIsTooHighLevel, const char *tempLabel) {
  tempSensorNr = currentTempSensor++;
  theTempIsHighLevel = tempIsHighLevel;
	theTempIsTooHighLevel = tempIsTooHighLevel;
  conversionTime = MAX_TEMP_CONVERSIONTIME / (1 << (12 - TEMP_RESOLUTION));
  sprintf(labelTempSensor, "%s", tempLabel);
}

void TemperatureSensor::begin() {
  tempIsHigh = false;
  ErrorTempIsTooHigh = false;
  if (tempSensorNr == 0) {
    sensorTemp.begin();
  }

  tempSensorAvailable = sensorTemp.getAddress(tempDeviceAddress, tempSensorNr);
  if (!tempSensorAvailable) {
    temperature = -127;

    Log.print("Temperature sensor ");
    Log.print(tempSensorNr + 1);
    Log.print(" (");
    Log.print(labelTempSensor);
    Log.println("): sensor not detected at init of node!");
    return;
  }
  sensorTemp.setResolution(tempDeviceAddress, TEMP_RESOLUTION);
  sensorTemp.setWaitForConversion(false);
  sensorTemp.requestTemperaturesByAddress(tempDeviceAddress);
  tempAvailableStartTime = millis();
  tryCount = MAX_NR_OF_TRIES;
}

void TemperatureSensor::loop() {
  if (!tempSensorAvailable) {
    return;
  }
  if ((millis() - tempAvailableStartTime) > conversionTime) {
    currentTemperature = sensorTemp.getTempC(tempDeviceAddress);
    if (currentTemperature == -127) {
      currentTemperature = sensorTemp.getTempC(tempDeviceAddress);
    }
    if (currentTemperature == -127) {
      if (tryCount > 0) {
        tryCount--;
        tempAvailableStartTime = millis();
        return;
      } else {
        Log.print("Temperature sensor ");
        Log.print(tempSensorNr + 1);
        Log.print(" (");
        Log.print(labelTempSensor);
        Log.println("): sensor does not react, perhaps not available?");
      }
    } else {
      if (currentTemperature != previousTemperature) {
        previousTemperature = currentTemperature;
        temperature = currentTemperature;
/*        
        Serial.print("Temperature ");
        Serial.print(tempSensor + 1);
        Serial.print(" changed, current temperature = ");
        Serial.print(temperature);
        Serial.println(" degrees C");
*/        
      }
    }
    tryCount = MAX_NR_OF_TRIES;
    sensorTemp.requestTemperaturesByAddress(tempDeviceAddress);
    tempAvailableStartTime = millis();
    if (temperature <= theTempIsHighLevel) {
      if (tempIsHigh) {
        Log.print("Temperature sensor ");
        Log.print(tempSensorNr + 1);
        Log.print(" (");
        Log.print(labelTempSensor);
        Log.println("): temperature is OK now (below warning threshold)");
      }
      tempIsHigh = false;
      if (ErrorTempIsTooHigh)
      {
        nextTimeDisplay = true;
      }
      ErrorTempIsTooHigh = false;
      tempIsTooHighStartTime = 0;
    } else {
      if (!tempIsHigh) {
        Log.print("WARNING: temperature sensor ");
        Log.print(tempSensorNr + 1);
        Log.print(" (");
        Log.print(labelTempSensor);
        Log.println("): temperature is above warning level. Please check the compressor");
      }
      tempIsHigh = true;
      if ((temperature > theTempIsTooHighLevel) && !ErrorTempIsTooHigh) {
        if (tempIsTooHighStartTime == 0) {
          tempIsTooHighStartTime = millis();
        } else {
          if ((millis() - tempIsTooHighStartTime) > MAX_TEMP_IS_TOO_HIGH_WINDOW) {
            nextTimeDisplay = true;
            ErrorTempIsTooHigh = true;
            Log.print("ERROR, sensor ");
            Log.print(tempSensorNr + 1);
            Log.print(" (");
            Log.print(labelTempSensor);
            Log.println("): Temperature is too high, compressor is disabled. Please check the compressor!");
          }
        }
      } else {
        if ((temperature <= theTempIsTooHighLevel) && ErrorTempIsTooHigh) {
          tempIsTooHighStartTime = 0;
          ErrorTempIsTooHigh = false;
          nextTimeDisplay = true;
          Log.print("WARNING, sensor ");
          Log.print(tempSensorNr + 1);
          Log.print(" (");
          Log.print(labelTempSensor);
          Log.println("): Temperature is below error level now, but still above warning level. Please check the compressor!");
        }
      }
    }
  }
}

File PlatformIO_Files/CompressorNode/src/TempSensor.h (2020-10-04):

#pragma once

#include <DallasTemperature.h> // install DallasTemperature by Miles Burton

class TemperatureSensor {

private:
    int tempSensorNr;
	DeviceAddress tempDeviceAddress;
	bool tempSensorAvailable = false;
	float currentTemperature;
	float theTempIsHighLevel;
	float theTempIsTooHighLevel;
	float previousTemperature = -500;
	unsigned long conversionTime;
	unsigned long tempAvailableStartTime = 0;
	unsigned long tempIsTooHighStartTime = 0;
	int tryCount;
	char labelTempSensor[20];

public:
  float temperature;
  bool tempIsHigh;
  bool ErrorTempIsTooHigh;

  TemperatureSensor(float tempIsHighLevel, float tempIsTooHighLevel, const char *tempLabel);

  void begin();
  
  void loop();
};

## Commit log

2020-10-04 first release of complete NodeCompressor project
    [Calibratie ADC ESP32.xlsx, CompressorNode 230V beveiliging V0.1 20200430.dxf, CompressorNode frontplaat txt font V0.2 20200501.dxf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]
2020-10-07 Changed the way how the compressor is switched off
2020-11-12 V0.18 Concept solved some issues
    [OledDisplay.cpp]
2021-01-05 V0.19, reboot at 01:00 AM and added automatic extend the automatic timeout time
    [TempSensor.cpp, main.cpp]
